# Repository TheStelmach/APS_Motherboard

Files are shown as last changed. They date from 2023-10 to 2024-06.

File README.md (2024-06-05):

# PeekAntenna

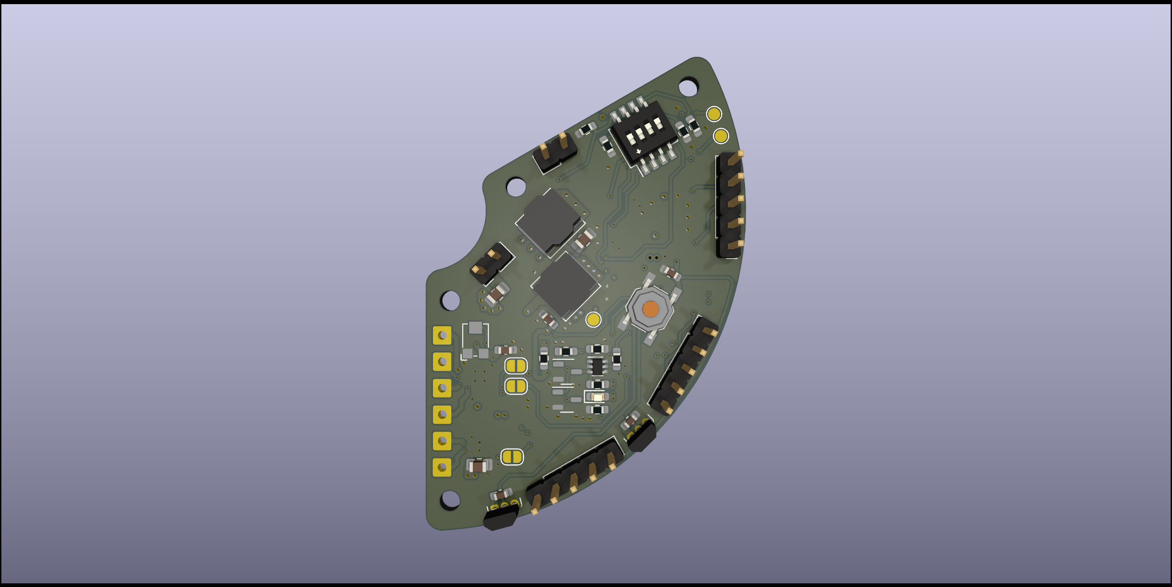
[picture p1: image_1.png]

Render 1

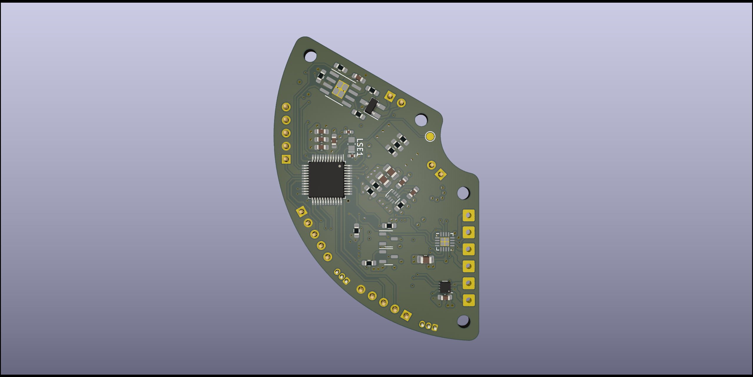
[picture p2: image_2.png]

Render 2

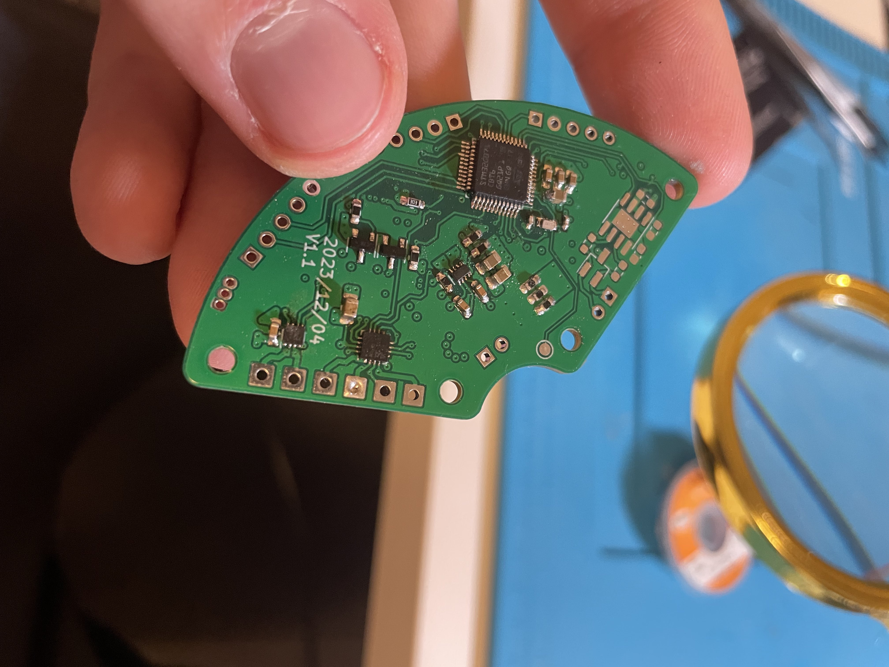
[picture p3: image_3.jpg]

Board partially assembled and debugged

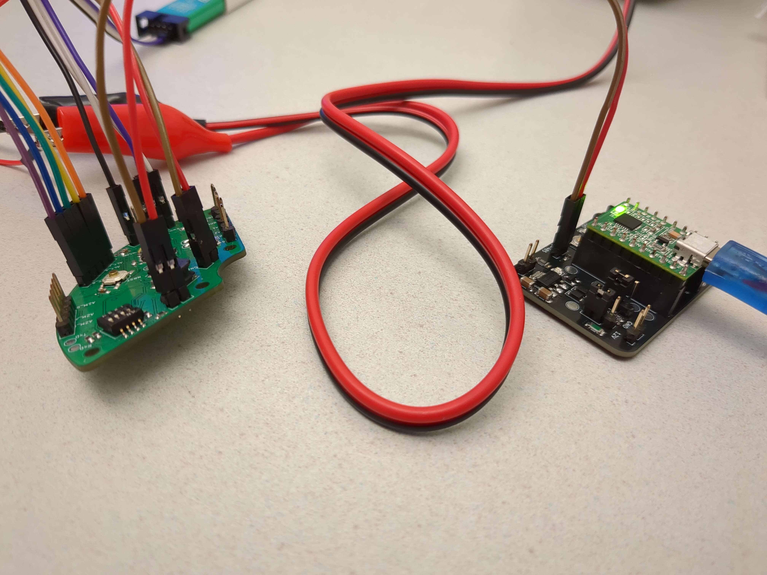
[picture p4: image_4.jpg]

Board communicated with by the custom RS-485 transceiver board, link below.

https://github.com/TheStelmach/UART_to_RS-485_V1/tree/main

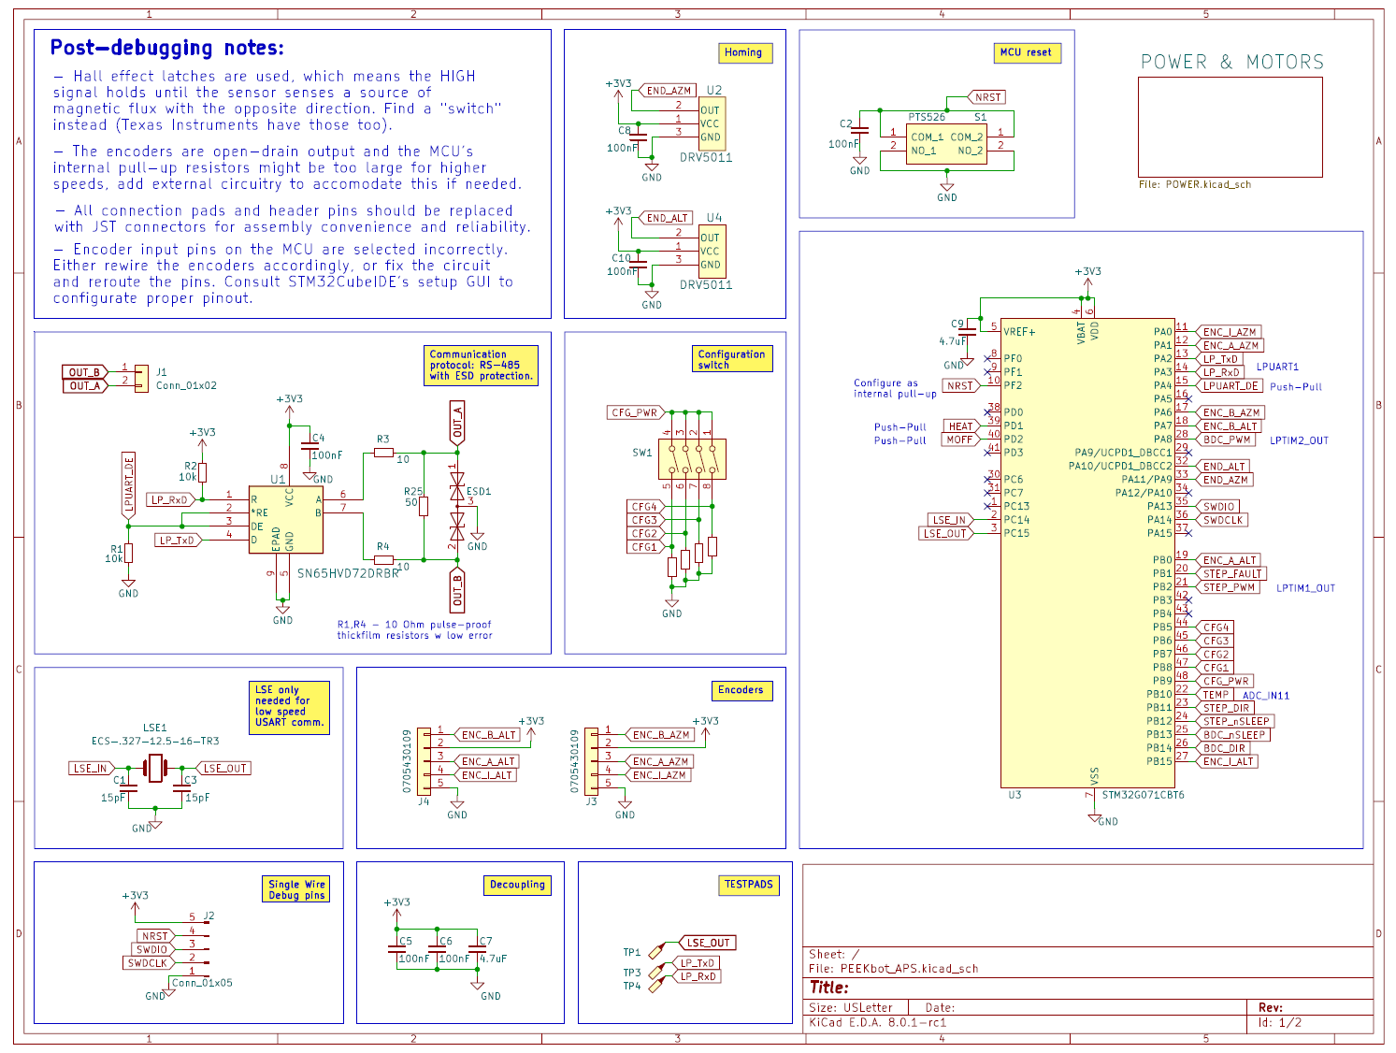
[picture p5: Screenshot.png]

Schematics Overview

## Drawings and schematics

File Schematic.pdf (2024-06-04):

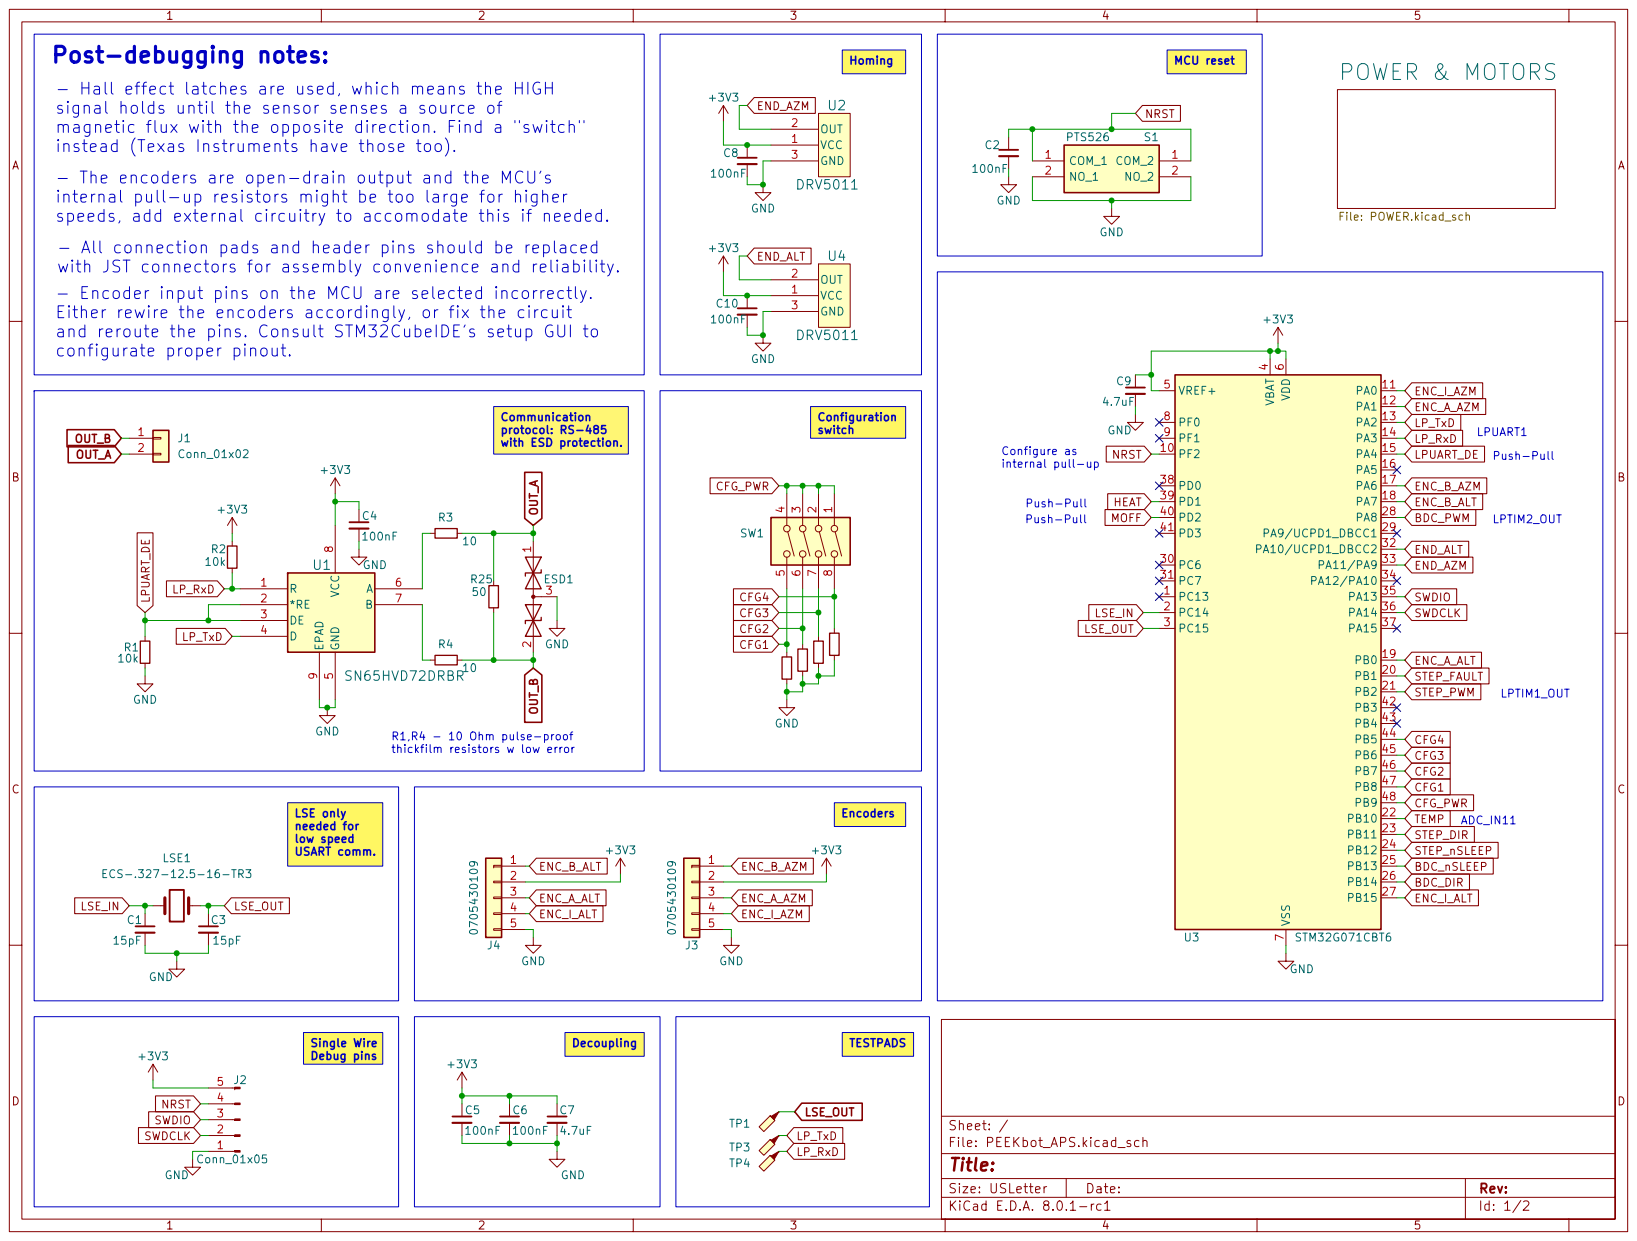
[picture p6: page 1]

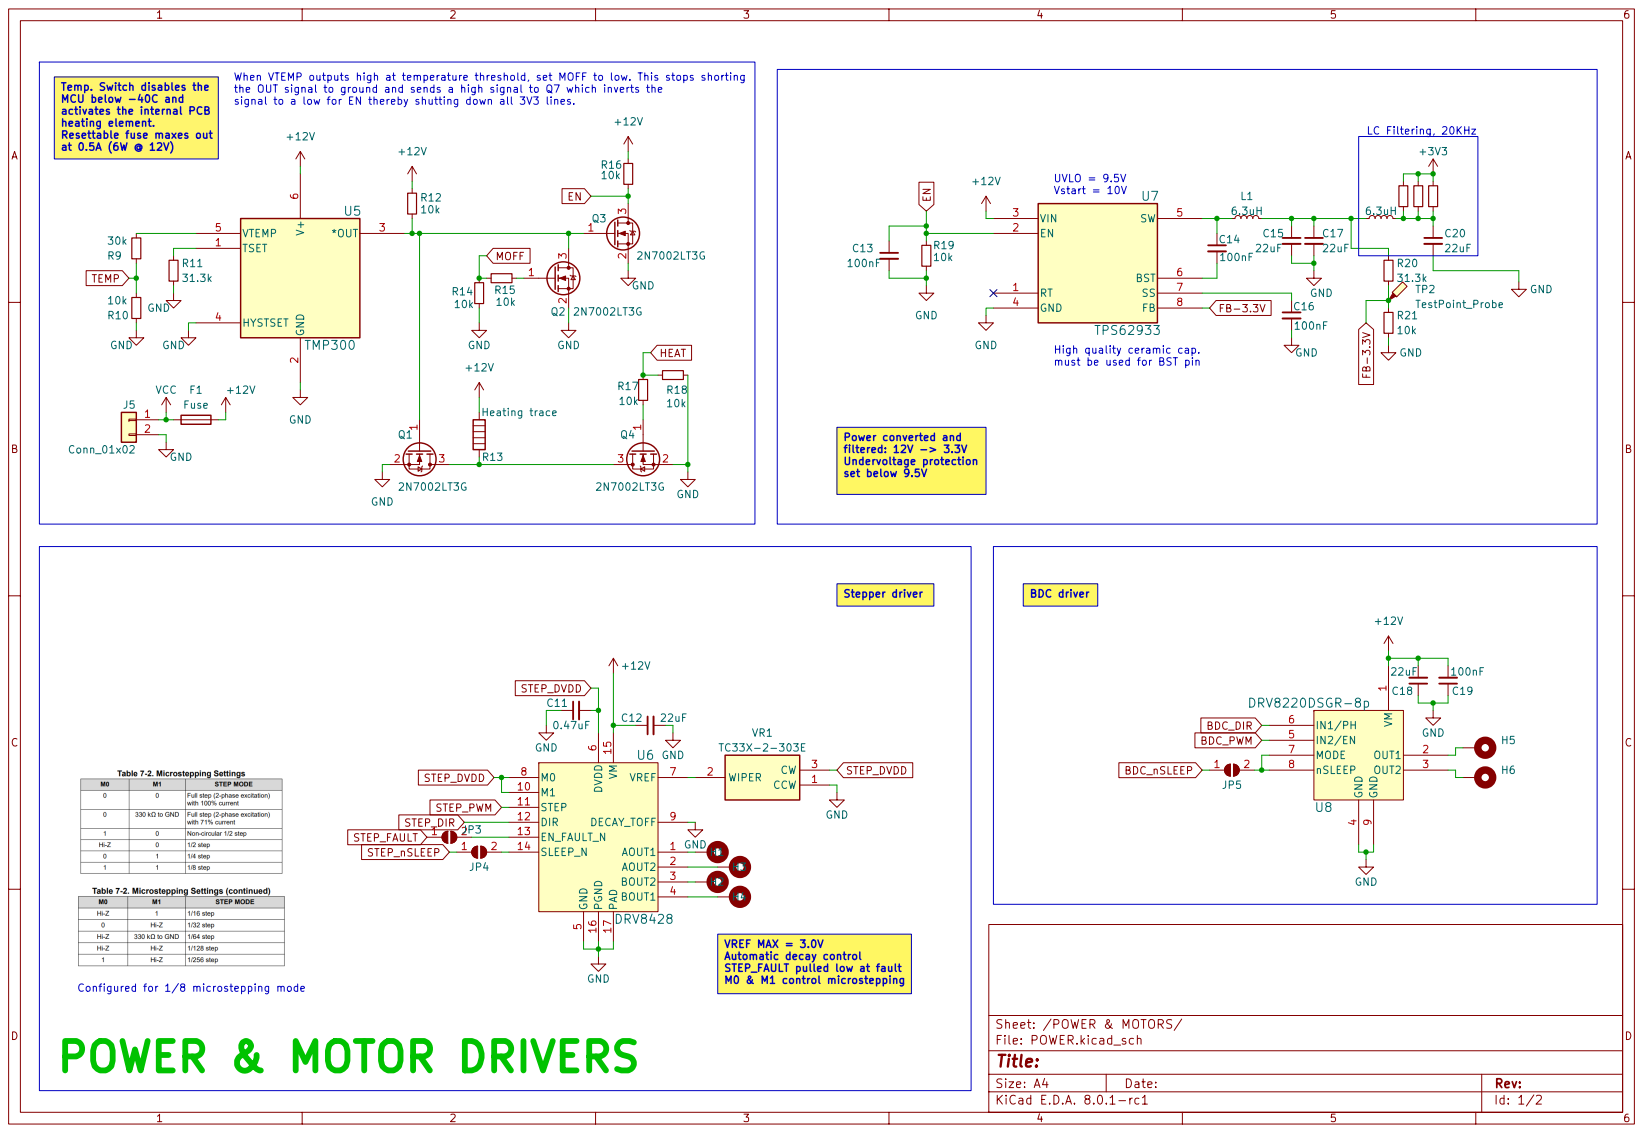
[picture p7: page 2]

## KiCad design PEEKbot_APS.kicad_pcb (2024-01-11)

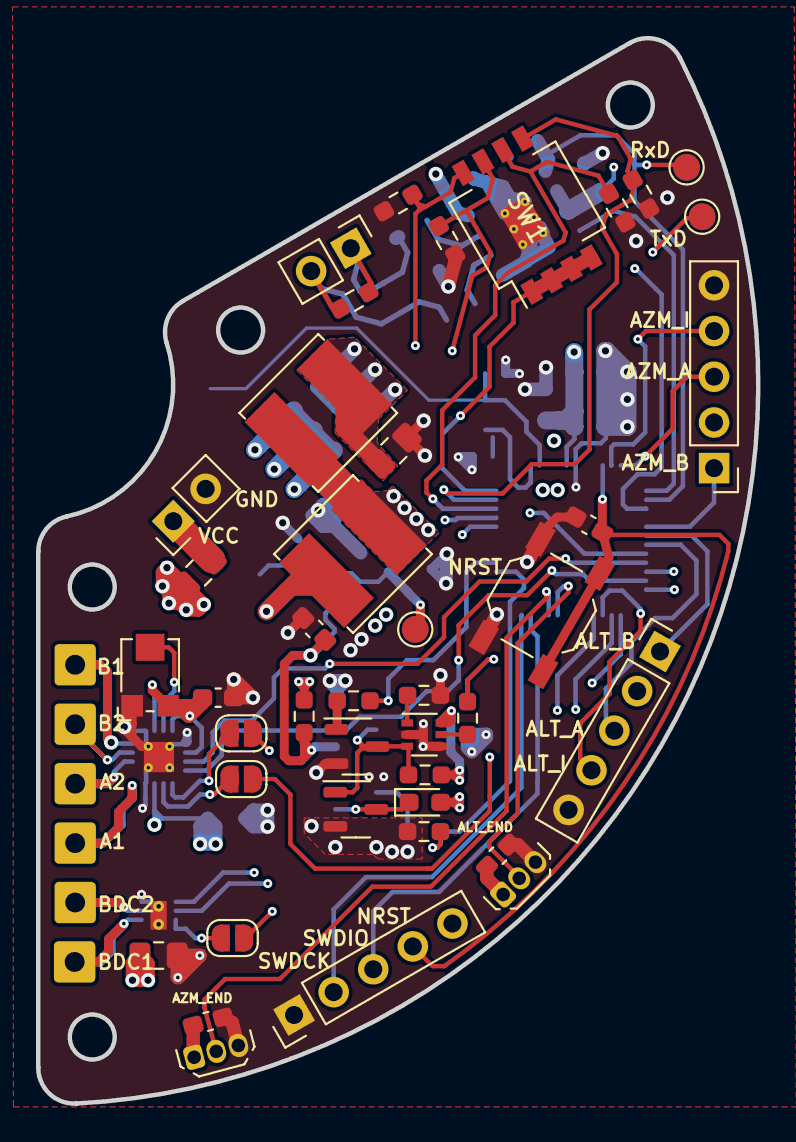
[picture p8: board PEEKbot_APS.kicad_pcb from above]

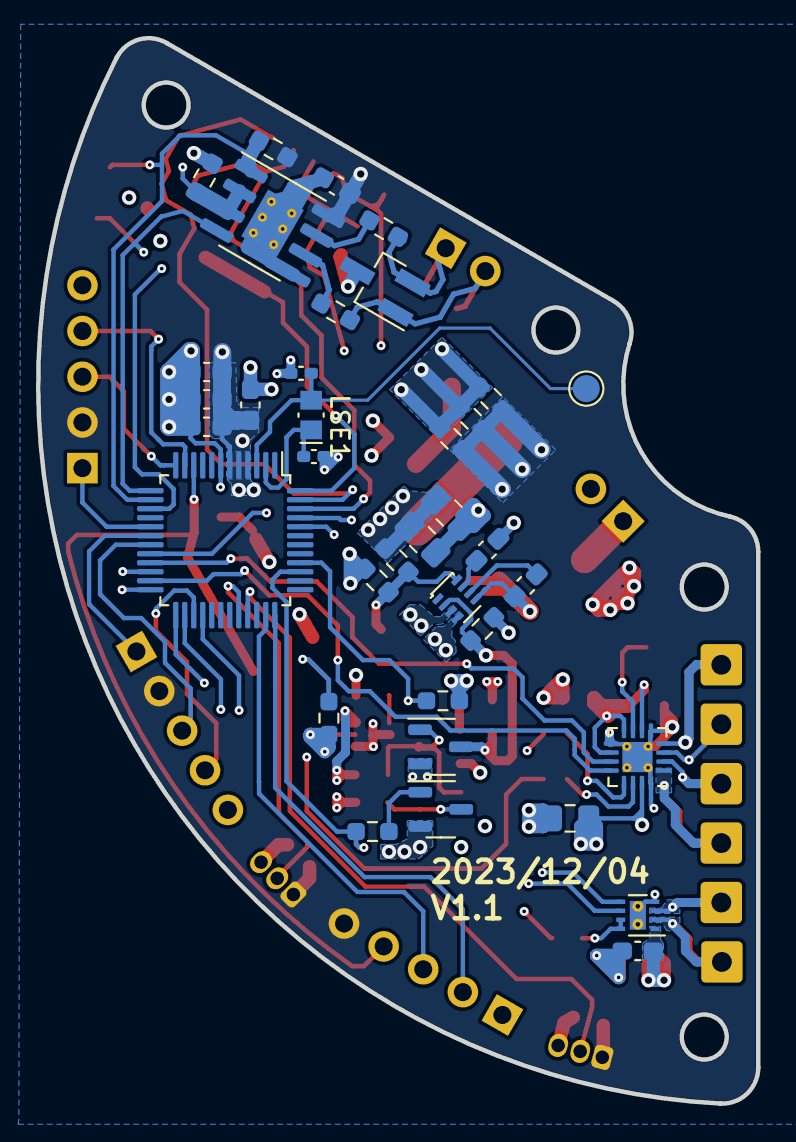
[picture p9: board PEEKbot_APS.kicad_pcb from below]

Board: 4 copper layers, 40.0 x 59.2 mm, 83 parts (36 on the bottom side), 63 nets.

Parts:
C1, C3: 15pF; C_0402_1005Metric_Pad0.74x0.62mm_HandSolder
C2, C4, C5, C6, C8, C10, C13, C14, C16, C19: 100nF; C_0603_1608Metric_Pad1.08x0.95mm_HandSolder
C7, C9: 4.7uF; C_0603_1608Metric_Pad1.08x0.95mm_HandSolder
C11: 0.47uF; C_0603_1608Metric_Pad1.08x0.95mm_HandSolder
C12, C15, C17, C18, C20: 22uF; C_0805_2012Metric_Pad1.18x1.45mm_HandSolder
ESD1: SM712_SOT23; SOT-23_Handsoldering
F1: Fuse; C_0805_2012Metric_Pad1.18x1.45mm_HandSolder
H1, H2, H3, H4, H5, H6: MountingHole_Pad; SolderWire-0.5sqmm_1x01_D0.9mm_OD2.3mm
J1, J5: Conn_01x02; PinHeader_1x02_P2.54mm_Vertical
J2: Conn_01x05; PinHeader_1x05_P2.54mm_Vertical
J3, J4: 0705430109; PinHeader_1x05_P2.54mm_Vertical
JP3, JP4, JP5: SolderJumper_2_Open; SolderJumper-2_P1.3mm_Open_RoundedPad1.0x1.5mm
L1, L2: 6.3uH; L_Bourns_SRN6045TA
LSE1: ECS-.327-12.5-16-TR3; Crystal_SMD_MicroCrystal_CM9V-T1A-2Pin_1.6x1.0mm_HandSolder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
Q1, Q2, Q3, Q4: 2N7002LT3G; SOT-23-3
R1, R2, R5, R6, R7, R8, R10, R12, R14, R15, R16, R17, R18, R19, R21: 10k; R_0603_1608Metric_Pad0.98x0.95mm_HandSolder
R3, R4: 10; R_0603_1608Metric_Pad0.98x0.95mm_HandSolder
R9: 30k; R_0603_1608Metric_Pad0.98x0.95mm_HandSolder
R11, R20: 31.3k; R_0603_1608Metric_Pad0.98x0.95mm_HandSolder
R13: Heater; LED_0603_1608Metric_Pad1.05x0.95mm_HandSolder
R22, R23, R24: 0; R_0603_1608Metric_Pad0.98x0.95mm_HandSolder
R25: 50; R_0603_1608Metric_Pad0.98x0.95mm_HandSolder
S1: PTS526; SW_SPST_TL3342
SW1: SW_DIP_x04; SW_DIP_SPSTx04_Slide_KingTek_DSHP04TS_W7.62mm_P1.27mm
TP1, TP2, TP3, TP4: TestPoint_Probe; TestPoint_Pad_D1.5mm
U1: SN65HVD72DRBR; SOIC-8-1EP_3.9x4.9mm_P1.27mm_EP2.29x3mm_ThermalVias
U2, U4: DRV5011; TO-92Flat
U3: STM32G071CBT6; LQFP-48_7x7mm_P0.5mm
U5: TMP300; SOT-363_SC-70-6
U6: DRV8428; WQFN-16-1EP_3x3mm_P0.5mm_EP1.68x1.68mm_ThermalVias
U7: TPS62933; SOT-583-8
U8: DRV8220DSGR-8p; WSON-8-1EP_2x2mm_P0.5mm_EP0.9x1.6mm_ThermalVias
VR1: TC33X-2-303E; Potentiometer_Bourns_TC33X_Vertical

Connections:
+3V3: C4.1, C5.1, C6.1, C7.1, C8.1, C9.1, C10.1, J2.5, J3.2, J4.2, R2.1, R22.1, R23.1, R24.1, U1.8 (VCC), U2.1 (VCC), U3.4 (VBAT), U3.5 (VREF+), U3.6 (VDD), U4.1 (VCC)
+12V: C12.1, C18.2, C19.2, F1.2, R12.1, R13.2, R16.1, U5.6 (V+), U6.15 (VM), U7.3 (VIN), U8.1 (VM)
BDC_DIR: U3.26 (PB14), U8.6 (IN1/PH)
BDC_PWM: U3.28 (PA8), U8.5 (IN2/EN)
BDC_nSLEEP: JP5.1 (A), U3.25 (PB13)
CFG1: R5.1, SW1.5, U3.47 (PB8)
CFG2: R6.1, SW1.6, U3.46 (PB7)
CFG3: R7.1, SW1.7, U3.45 (PB6)
CFG4: R8.1, SW1.8, U3.44 (PB5)
CFG_PWR: SW1.1, SW1.2, SW1.3, SW1.4, U3.48 (PB9)
EN: C13.1, Q3.3 (D), R16.2, R19.1, U7.2 (EN)
ENC_A_ALT: J4.3, U3.19 (PB0)
ENC_A_AZM: J3.3, U3.12 (PA1)
ENC_B_ALT: J4.1, U3.18 (PA7)
ENC_B_AZM: J3.1, U3.17 (PA6)
ENC_I_ALT: J4.4, U3.27 (PB15)
ENC_I_AZM: J3.4, U3.11 (PA0)
END_ALT: U3.32 (PA10/UCPD1_DBCC2), U4.2 (OUT)
END_AZM: U2.2 (OUT), U3.33 (PA11/PA9)
FB-3.3V: R20.1, R21.1, TP2.1, U7.8 (FB)
GND: C1.2, C2.2, C3.2, C4.2, C5.2, C6.2, C7.2, C8.2, C9.2, C10.2, C11.1, C12.2, C13.2, C15.2, C16.2, C17.2, C18.1, C19.1, C20.2, ESD1.3 (common), J2.1, J3.5, J4.5, J5.2, Q1.2 (S), Q2.2 (S), Q3.2 (S), Q4.2 (S), R1.2, R5.2, R6.2, R7.2, R8.2, R10.2, R11.1, R14.2, R18.2, R19.2, R21.2, S1.2 (NO), U1.5 (GND), U1.9 (EPAD), U2.3 (GND), U3.7 (VSS), U4.3 (GND), U5.2 (GND), U5.4 (HYSTSET), U6.5 (GND), U6.9 (DECAY_TOFF), U6.16 (PGND), U6.17 (PAD), U7.4 (GND), U8.4 (GND), U8.9 (GND), VR1.1 (CCW)
HEAT: R17.1, R18.1, U3.39 (PD1)
LPUART_DE: R1.1, U1.2 (*RE), U1.3 (DE), U3.15 (PA4)
LP_RxD: R2.2, TP4.1, U1.1 (R), U3.14 (PA3)
LP_TxD: TP3.1, U1.4 (D), U3.13 (PA2)
LSE_IN: C1.1, LSE1.1, U3.2 (PC14)
LSE_OUT: C3.1, LSE1.2, TP1.1, U3.3 (PC15)
MOFF: R14.1, R15.2, U3.40 (PD2)
NRST: C2.1, J2.4, S1.1 (COM), U3.10 (PF2)
unnamed: C15.1, C17.1, L1.2, L2.1, R20.2
unnamed: C20.1, L2.2, R22.2, R23.2, R24.2
unnamed: JP3.2 (B), U6.13 (EN_FAULT_N)
unnamed: JP4.2 (B), U6.14 (SLEEP_N)
unnamed: JP5.2 (B), U8.7 (MODE), U8.8 (nSLEEP)
unnamed: Q1.3 (D), Q4.3 (D), R13.1
unnamed: Q1.1 (G), Q2.3 (D), Q3.1 (G), R12.2, U5.3 (*OUT)
unnamed: Q2.1 (G), R15.1
unnamed: Q4.1 (G), R17.2
unnamed: R3.2, U1.6 (A)
unnamed: R4.2, U1.7 (B)
unnamed: R11.2, U5.1 (TSET)
unnamed: R9.1, U5.5 (VTEMP)
unnamed: H1.1, U6.1 (AOUT1)
unnamed: H3.1, U6.2 (AOUT2)
unnamed: H4.1, U6.4 (BOUT1)
unnamed: H2.1, U6.3 (BOUT2)
unnamed: U6.7 (VREF), VR1.2 (WIPER)
unnamed: C14.2, U7.6 (BST)
unnamed: C16.1, U7.7 (SS)
unnamed: C14.1, L1.1, U7.5 (SW)
unnamed: H5.1, U8.2 (OUT1)
unnamed: H6.1, U8.3 (OUT2)
OUT_A: ESD1.1 (A1), J1.2, R3.1, R25.1
OUT_B: ESD1.2 (A2), J1.1, R4.1, R25.2
STEP_DIR: U3.23 (PB11), U6.12 (DIR)
STEP_DVDD: C11.2, U6.6 (DVDD), U6.8 (M0), U6.10 (M1), VR1.3 (CW)
STEP_FAULT: JP3.1 (A), U3.20 (PB1)
STEP_PWM: U3.21 (PB2), U6.11 (STEP)
STEP_nSLEEP: JP4.1 (A), U3.24 (PB12)
SWDCLK: J2.2, U3.36 (PA14)
SWDIO: J2.3, U3.35 (PA13)
TEMP: R9.2, R10.1, U3.22 (PB10)
VCC: F1.1, J5.1

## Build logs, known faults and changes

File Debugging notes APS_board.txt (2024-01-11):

2023/12/27

-Use SOIC packages for the two motor drivers for convenient handsoldering. The packages currently used are too small.
-DRV5011 has internal deglitching, no need for the capacitors.
-The encoders are open-drain output and the MCU's internal pull-up resistors might be too large for higher speeds, add pull-up resistors to encoder outputs.
-SN65HVD72DRBR - wrong package & footprint combination. Make an adjustment and use a SOIC package for everything.
-Hall effect latches are used, which means the HIGH signal holds until the sensor senses an opposite direction magnetic flux source. Find a switch instead (Texas Instruments has those)
-Prior to ordering the second iteration of PCB, configure all the pins on STM32CubeIDE first and confirm that there are no warnings.
-UART testpads should be made slightly bigger and located closer to the internal side of the PCB, if possible.
-Motor connection pads should be standardized for convenience during setup.

2023/12/29

-The BDC driver circuitry works well but the inrush current of the BDC motor is too high. The internal protection circuitry doesn't like it and switches off the power supply. Therefore, an inrush current limiter MUST be added to the board.
-The internal heating simulation LED needs a 10k resitor added, it was not added at first because a 100 Ohm resistor was planned to be placed instead.
-It is worth mentioning that the PCB with all external peripherals disconnected and the MCU running at 16Mhz and performing constant computations consumes under 25mA at 12V, which is a decent power consumption efficiency for a commercial product already, considering the on-board power conversion circuitry. The actual program will keep the MCU running either in low power mode driven by the RTC or at 2MHz at all times.

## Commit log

2023-10-08 Add files via upload
    H-bridges for BDC motors replaced with simple BLDC motor drivers (speed control only);
    Some 0 Ohm resistors replaced with bridge pads;
    All footprints assigned to components (Need to be reviewed, some footprints should be smaller);
    Started working on the PCB design
    [PEEKbot_APS.kicad_pcb, PEEKbot_APS.kicad_sch]
2024-01-11 Add files via upload
    1st iteration finalized. The board has been tested and partially debugged. Comments can be found in the txt file.
    [COMMS.kicad_sch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]
